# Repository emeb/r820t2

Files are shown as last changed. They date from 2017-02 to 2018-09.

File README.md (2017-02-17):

# r820t2
Breakout PCB design and STM32F0 firmware for the Rafael R820T2 tuner chip

Contents
--------

doc - documents for the chip and PCB design. This includes both the orginal
mfgs datasheet as well as schematic and BOM for the PCB design.

f030_r820t2 - STM32F030 firmware. A simple serial command line interface
to access registers and set frequency & gain parameters.

r820t2_breakout - KiCAD PCB design.

LICENSE
-------

The PCB design is licensed separately from the driver code. Please see
the LICENSE files within each sub-directory.

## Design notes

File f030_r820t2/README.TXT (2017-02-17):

README.TXT

Building
--------

Just run
	make
	
Flashing
--------

1) Ensure openocd isn't running as a server already.

2) Make sure that your STM32F0 Discovery board is connected via USB and the
ST-LINK jumpers are set correctly (this example is for the on-board processor,
so 1-2 and 3-4 should be shorted)

3) run
	make flash

4) Done!

Debugging
---------

1) in a separate window start up openocd as a GDB server
	openocd -f openocd.cfg

2) run gdb with your favorite UI
	ddd --debugger arm-none-eabi-gdb main.elf

3) connect to the server within gdb
	target extended-remote localhost:3333

4) Start debugging!

LICENSE
-------

The r820t2 driver code (r820t2.[ch]) herein originated with the Airspy product
which derived from the Linux driver. Consequently my revisions are subject to
the LICENSE file from those projects.

The CMSIS and StdPeriph directories are from ARM ans ST Microelectronics and
are suject to the licenses therein.

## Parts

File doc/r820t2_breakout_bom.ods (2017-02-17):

Reference | Value | Footprint | Cnt | Qty | Mfg P/N | Distributor | Distributor P/N | Notes
C101 | 0.01uf | Capacitors_SMD:C_0603_HandSoldering | 1 | 1 | C1608X7R1H103K080AA | Mouser | 810-C1608X7R1H103K
C108 | 0.1uf | Capacitors_SMD:C_0603_HandSoldering | 1
C116 | 0.1uf | Capacitors_SMD:C_0603_HandSoldering | 1
C117 | 0.1uf | Capacitors_SMD:C_0603_HandSoldering | 1
C104 | 0.1uf | Capacitors_SMD:C_0603_HandSoldering | 1
C109 | 0.1uf | Capacitors_SMD:C_0603_HandSoldering | 1
C113 | 0.1uf | Capacitors_SMD:C_0603_HandSoldering | 1
C114 | 0.1uf | Capacitors_SMD:C_0603_HandSoldering | 1
C118 | 0.1uf | Capacitors_SMD:C_0603_HandSoldering | 1
C121 | 0.1uf | Capacitors_SMD:C_0603_HandSoldering | 1
C103 | 0.1uf | Capacitors_SMD:C_0603_HandSoldering | 1 | 10 | C1608X7R1E104K080AA | Digi-Key | 445-1316-1-ND
C106 | 1uf | Capacitors_SMD:C_0603_HandSoldering | 1 | 1 | GCM188R71E105KA64D | Mouser | 81-GCM188R71E105KA4D
C110 | 27pf | Capacitors_SMD:C_0603_HandSoldering | 1
C111 | 27pf | Capacitors_SMD:C_0603_HandSoldering | 1
C105 | 27pf | Capacitors_SMD:C_0603_HandSoldering | 1
C107 | 27pf | Capacitors_SMD:C_0603_HandSoldering | 1 | 4 | CL10C270JB8NNNC | Digi-Key | 1276-1086-1-ND
C102 | 330pf | Capacitors_SMD:C_0603_HandSoldering | 1
C119 | 330pf | Capacitors_SMD:C_0603_HandSoldering | 1 | 2 | C0603C331J5GACTU | Digi-Key | 399-1068-1-ND
C120 | 6800pf | Capacitors_SMD:C_0603_HandSoldering | 1 | 1 | GRM1885C1H682JA01D | Digi-Key | 490-11477-1-ND
C112 | 10uf | Capacitors_SMD:C_0805_HandSoldering | 1
C115 | 10uf | Capacitors_SMD:C_0805_HandSoldering | 1 | 2 | EMK212BB7106MG-T | Mouser | 963-EMK212BB7106MG-T
P102 | DNI | Connect:PINTST | 1
P103 | DNI | Connect:PINTST | 1
P108 | DNI | Connect:PINTST | 1
P106 | DNI | Connect:PINTST | 1
P104 | DNI | Connect:PINTST | 1
P107 | DNI | Connect:PINTST | 1
P105 | DNI | Connect:PINTST | 1 | 7
U101 | TWEAALSANF-28.800000 | Crystals:Crystal_SMD_Abracon_ABM3C-4pin_5.0x3.2mm | 1 | 1
Y101 | 28.8MHz | Crystals:Crystal_SMD_HC49-SD | 1 | 1 | 9C-28.800MBBK-T | Digi-Key | 887-2449-1-ND
T101 | TRANSFO4 | footprints:Pulse_SMD_Balun | 1 | 1 | MABAES0060 | Digi-Key | 1465-1317-1-ND
U102 | R820T2 | footprints:QFN-24-1EP_4x4mm_Pitch0.5mm_extended_pad | 1 | 1 | R820T2 | ebay
J101 | SMA | footprints:SMA_END | 1
J102 | SMA | footprints:SMA_END | 1 | 2 | Misc SMA end-launch | ebay
P101 | CONN_01X04 | Pin_Headers:Pin_Header_Straight_1x04_Pitch2.54mm | 1 | 1 | Generic 0.1” breakaway
R111 | 0 | Resistors_SMD:R_0603_HandSoldering | 1
R105 | 0 | Resistors_SMD:R_0603_HandSoldering | 1 | 2 | ERJ-3GEY0R00V | Digi-Key | P0.0GCT-ND
R106 | 10 | Resistors_SMD:R_0603_HandSoldering | 1 | 1 | ERJ-3GEYJ100V | Digi-Key | P10GCT-ND
R101 | 220 | Resistors_SMD:R_0603_HandSoldering | 1
R102 | 220 | Resistors_SMD:R_0603_HandSoldering | 1
R107 | 220 | Resistors_SMD:R_0603_HandSoldering | 1
R108 | 220 | Resistors_SMD:R_0603_HandSoldering | 1 | 4 | ERJ-3GEYJ221V | Digi-Key | P220GCT-ND
R112 | 10k | Resistors_SMD:R_0603_HandSoldering | 1 | 1 | ERJ-3GEYJ103V | Digi-Key | P10KGCT-ND
L102 | 150nh | Resistors_SMD:R_0603_HandSoldering | 1
L103 | 150nh | Resistors_SMD:R_0603_HandSoldering | 1 | 2 | L-14CR15JV4T | Digi-Key | 712-1448-1-ND
R110 | 1k8 | Resistors_SMD:R_0603_HandSoldering | 1 | 1 | ERJ-3GEYJ182V | Digi-Key | P1.8KGCT-ND
R103 | 4k7 | Resistors_SMD:R_0603_HandSoldering | 1
R104 | 4k7 | Resistors_SMD:R_0603_HandSoldering | 1 | 2 | ERJ-3GEYJ472V | Digi-Key | P4.7KGCT-ND
L101 | 8.2nH | Resistors_SMD:R_0603_HandSoldering | 1 | 1 | LQW18AN8N2D00D | Digi-Key | 490-1167-1-ND
R109 | DNI | Resistors_SMD:R_0603_HandSoldering | 1 | 1
U103 | LD1117S33CTR | SOT-223 | 1 | 1 | LD1117S33TR | Digi-Key | 497-1242-1-ND
D101 | BAV99 | TO_SOT_Packages_SMD:SOT-23 | 1 | 1 | BAV99 | Digi-Key | BAV99FSCT-ND

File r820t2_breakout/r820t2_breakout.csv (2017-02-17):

Reference | Value | Footprint | Cnt | Qty | Mfg P/N | Distributor | Distributor P/N | Notes
C101 | 0.01uf | Capacitors_SMD:C_0603_HandSoldering | 1 | 1
C108 | 0.1uf | Capacitors_SMD:C_0603_HandSoldering | 1
C116 | 0.1uf | Capacitors_SMD:C_0603_HandSoldering | 1
C117 | 0.1uf | Capacitors_SMD:C_0603_HandSoldering | 1
C104 | 0.1uf | Capacitors_SMD:C_0603_HandSoldering | 1
C109 | 0.1uf | Capacitors_SMD:C_0603_HandSoldering | 1
C113 | 0.1uf | Capacitors_SMD:C_0603_HandSoldering | 1
C114 | 0.1uf | Capacitors_SMD:C_0603_HandSoldering | 1
C118 | 0.1uf | Capacitors_SMD:C_0603_HandSoldering | 1
C121 | 0.1uf | Capacitors_SMD:C_0603_HandSoldering | 1
C103 | 0.1uf | Capacitors_SMD:C_0603_HandSoldering | 1 | 10 | C1608X7R1E104K080AA | Digi-Key | 445-1316-1-ND
C106 | 1uf | Capacitors_SMD:C_0603_HandSoldering | 1 | 1 | GCM188R71E105KA64D | Mouser | 81-GCM188R71E105KA4D
C110 | 27pf | Capacitors_SMD:C_0603_HandSoldering | 1
C111 | 27pf | Capacitors_SMD:C_0603_HandSoldering | 1
C105 | 27pf | Capacitors_SMD:C_0603_HandSoldering | 1
C107 | 27pf | Capacitors_SMD:C_0603_HandSoldering | 1 | 4
C102 | 330pf | Capacitors_SMD:C_0603_HandSoldering | 1
C119 | 330pf | Capacitors_SMD:C_0603_HandSoldering | 1 | 2
C120 | 6800pf | Capacitors_SMD:C_0603_HandSoldering | 1 | 1
C112 | 10uf | Capacitors_SMD:C_0805_HandSoldering | 1
C115 | 10uf | Capacitors_SMD:C_0805_HandSoldering | 1 | 2 | EMK212BB7106MG-T | Mouser | 963-EMK212BB7106MG-T
P102 | DNI | Connect:PINTST | 1
P103 | DNI | Connect:PINTST | 1
P108 | DNI | Connect:PINTST | 1
P106 | DNI | Connect:PINTST | 1
P104 | DNI | Connect:PINTST | 1
P107 | DNI | Connect:PINTST | 1
P105 | DNI | Connect:PINTST | 1 | 7
U101 | TWEAALSANF-28.800000 | Crystals:Crystal_SMD_Abracon_ABM3C-4pin_5.0x3.2mm | 1 | 1
Y101 | 28.8MHz | Crystals:Crystal_SMD_HC49-SD | 1 | 1
T101 | TRANSFO4 | footprints:Pulse_SMD_Balun | 1 | 1
U102 | R820T2 | footprints:QFN-24-1EP_4x4mm_Pitch0.5mm_extended_pad | 1 | 1
J101 | SMA | footprints:SMA_END | 1
J102 | SMA | footprints:SMA_END | 1 | 2
P101 | CONN_01X04 | Pin_Headers:Pin_Header_Straight_1x04_Pitch2.54mm | 1 | 1
R111 | 0 | Resistors_SMD:R_0603_HandSoldering | 1
R105 | 0 | Resistors_SMD:R_0603_HandSoldering | 1 | 2
R106 | 10 | Resistors_SMD:R_0603_HandSoldering | 1 | 1
R101 | 220 | Resistors_SMD:R_0603_HandSoldering | 1
R102 | 220 | Resistors_SMD:R_0603_HandSoldering | 1
R107 | 220 | Resistors_SMD:R_0603_HandSoldering | 1
R108 | 220 | Resistors_SMD:R_0603_HandSoldering | 1 | 4
R112 | 10k | Resistors_SMD:R_0603_HandSoldering | 1 | 1
L102 | 150nh | Resistors_SMD:R_0603_HandSoldering | 1
L103 | 150nh | Resistors_SMD:R_0603_HandSoldering | 1 | 2
R110 | 1k8 | Resistors_SMD:R_0603_HandSoldering | 1 | 1
R103 | 4k7 | Resistors_SMD:R_0603_HandSoldering | 1
R104 | 4k7 | Resistors_SMD:R_0603_HandSoldering | 1 | 2
L101 | 8.2nH | Resistors_SMD:R_0603_HandSoldering | 1 | 1
R109 | DNI | Resistors_SMD:R_0603_HandSoldering | 1 | 1
U103 | LD1117S33CTR | SOT-223 | 1 | 1
D101 | BAV99 | TO_SOT_Packages_SMD:SOT-23 | 1 | 1

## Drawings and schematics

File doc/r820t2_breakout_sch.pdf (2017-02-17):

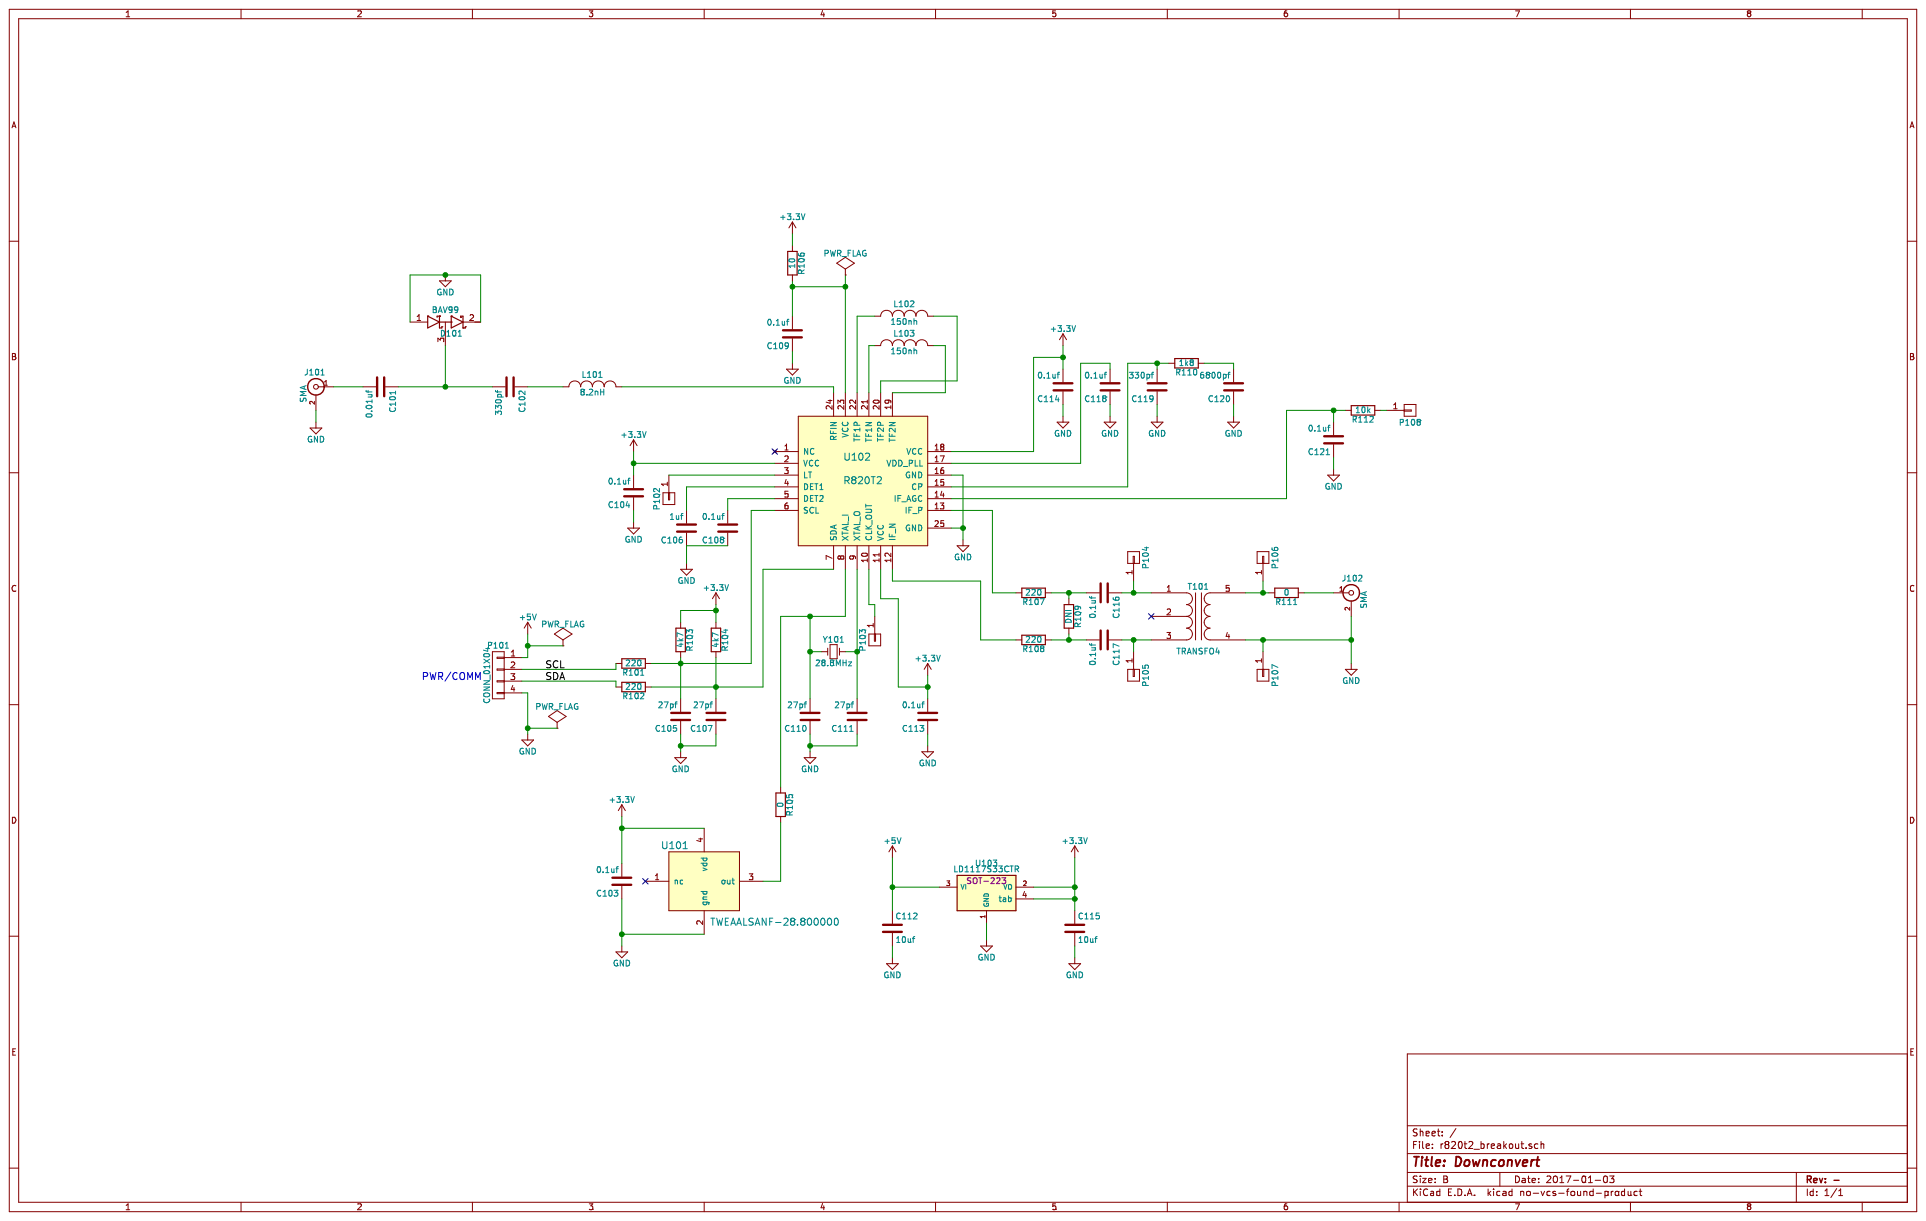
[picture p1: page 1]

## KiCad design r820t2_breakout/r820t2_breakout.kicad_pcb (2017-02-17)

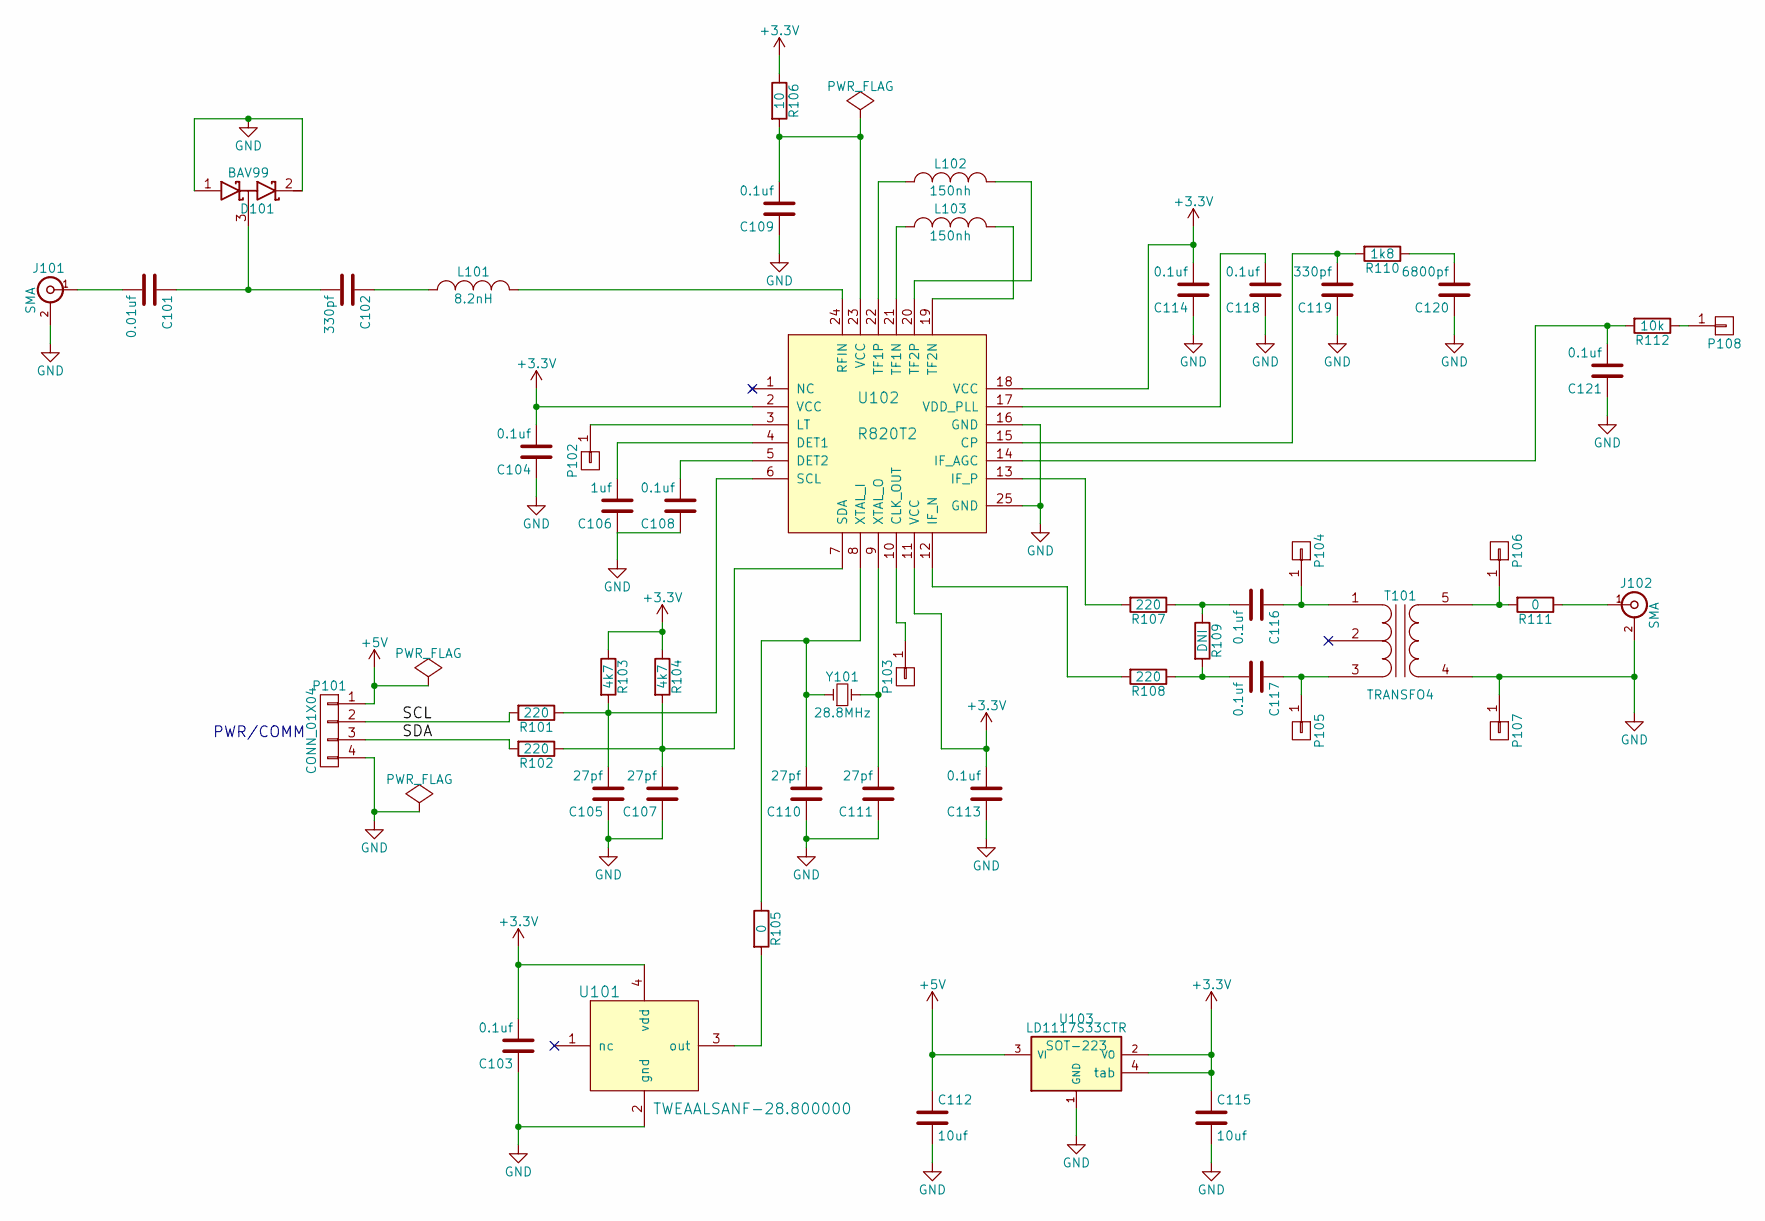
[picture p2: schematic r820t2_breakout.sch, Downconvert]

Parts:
C101: 0.01uf; C_0603_HandSoldering
C102, C119: 330pf; C_0603_HandSoldering
C103, C104, C108, C109, C113, C114, C116, C117, C118, C121: 0.1uf; C_0603_HandSoldering
C105, C107, C110, C111: 27pf; C_0603_HandSoldering
C106: 1uf; C_0603_HandSoldering
C112, C115: 10uf; C_0805_HandSoldering
C120: 6800pf; C_0603_HandSoldering
D101: BAV99; SOT-23
J101, J102: SMA; SMA_END
L101: 8.2nH; R_0603_HandSoldering
L102, L103: 150nh; R_0603_HandSoldering
P101: CONN_01X04; Pin_Header_Straight_1x04_Pitch2.54mm
P102, P103, P104, P105, P106, P107, P108: CONN_01X01; PINTST
R101, R102, R107, R108: 220; R_0603_HandSoldering
R103, R104: 4k7; R_0603_HandSoldering
R105, R111: 0; R_0603_HandSoldering
R106: 10; R_0603_HandSoldering
R109: DNI; R_0603_HandSoldering
R110: 1k8; R_0603_HandSoldering
R112: 10k; R_0603_HandSoldering
T101: TRANSFO4; Pulse_SMD_Balun
U101: TWEAALSANF-28.800000; Crystal_SMD_Abracon_ABM3C-4pin_5.0x3.2mm
U102: R820T2; QFN-24-1EP_4x4mm_Pitch0.5mm_extended_pad
U103: LD1117S33CTR; SOT-223
Y101: 28.8MHz; Crystal_SMD_HC49-SD

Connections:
+3V3: C103.2, C104.2, C113.2, C114.2, C115.1, R103.1, R104.1, R106.1, U101.4 (vdd), U102.2 (VCC), U102.11 (VCC), U102.18 (VCC), U103.2 (VO), U103.4 (tab)
+5V: C112.1, P101.1, U103.3 (VI)
/SCL: P101.2, R101.2
/SDA: P101.3, R102.2
GND: C103.1, C104.1, C105.1, C106.1, C107.1, C108.1, C109.1, C110.1, C111.1, C112.2, C113.1, C114.1, C115.2, C118.1, C119.1, C120.1, C121.1, D101.1 (A), D101.2 (K), J101.2 (Ext), J102.2 (Ext), P101.4, P107.1, T101.4 (S1), U101.2 (gnd), U102.16 (GND), U102.25 (GND), U103.1 (GND)
unnamed: C101.1, C102.2, D101.3 (common)
unnamed: C101.2, J101.1 (In)
unnamed: C102.1, L101.1
unnamed: C105.2, R101.1, R103.2, U102.6 (SCL)
unnamed: C106.2, U102.4 (DET1)
unnamed: C107.2, R102.1, R104.2, U102.7 (SDA)
unnamed: C108.2, U102.5 (DET2)
unnamed: C109.2, R106.2, U102.23 (VCC)
unnamed: C110.2, R105.1, U102.8 (XTAL_I), Y101.1
unnamed: C111.2, U102.9 (XTAL_O), Y101.2
unnamed: C116.1, P104.1, T101.1 (PR1)
unnamed: C116.2, R107.1, R109.1
unnamed: C117.1, P105.1, T101.3 (PR2)
unnamed: C117.2, R108.1, R109.2
unnamed: C118.2, U102.17 (VDD_PLL)
unnamed: C119.2, R110.2, U102.15 (CP)
unnamed: C120.2, R110.1
unnamed: C121.2, R112.2, U102.14 (IF_AGC)
unnamed: J102.1 (In), R111.1
unnamed: L101.2, U102.24 (RFIN)
unnamed: L102.1, U102.20 (TF2P)
unnamed: L102.2, U102.22 (TF1P)
unnamed: L103.1, U102.19 (TF2N)
unnamed: L103.2, U102.21 (TF1N)
unnamed: P102.1, U102.3 (LT)
unnamed: P103.1, U102.10 (CLK_OUT)
unnamed: P106.1, R111.2, T101.5 (S2)
unnamed: P108.1, R112.1
unnamed: R105.2, U101.3 (out)
unnamed: R107.2, U102.13 (IF_P)
unnamed: R108.2, U102.12 (IF_N)

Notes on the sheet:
PWR/COMM

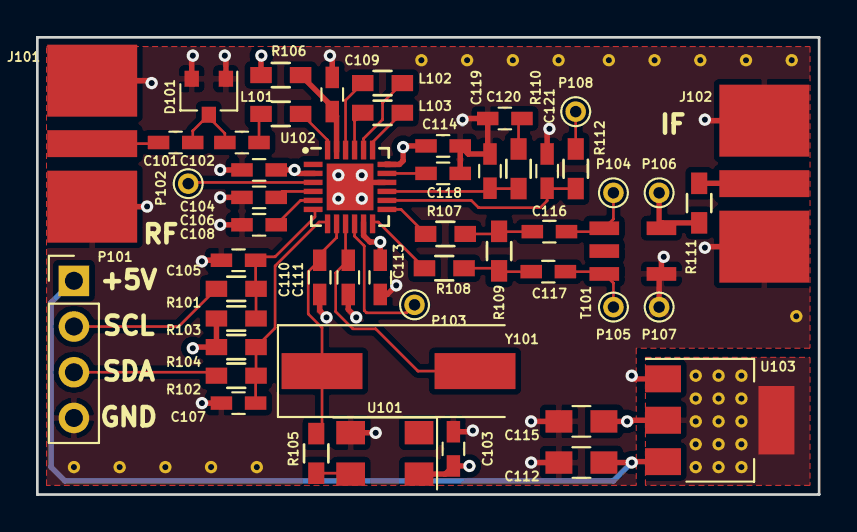
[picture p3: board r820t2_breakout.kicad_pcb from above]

Board: 4 copper layers, 43.4 x 25.4 mm, 52 parts (0 on the bottom side), 36 nets.

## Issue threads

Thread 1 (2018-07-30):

USING MINI DIGITAL TV STICK RTL2832U 820T2 & SDR ON GNRC

aecs18, 2018-07-30:
Good afternoon everyone.I write here to see if any of you know that installation errors I may have had to use the r820t2 in gnu radio companion.

I'm trying to make an FM receiver and other analog TV receiver but when running the program does not receive any type of signal and the view errors, I have: devices not supported. I believe that this is some driver to be installed but I don't know where or how.

The steps that I have followed for installation (Ubuntu 16.04 LTS) have been:

1. Install gnuradio.
2. Install Xenial Xerius specifications (it is supposed to do I need for my version of Ubuntu).
3. Install specifications of gr-osmosdr to enable some features of the chip.

The Stick comes with a CD but i do not know how to install it since, according to the specifications only works for WXP, 2000, Vista, 7 and 8; and it is something that it seems strange to me since I have seen videos where they use this same model of stick to carry out projects in Gnuradio on Ubuntu.

Please, if any of you know that i need to install It would serve as much help as I am a novice programmer and i need to resolve this problem for my project.

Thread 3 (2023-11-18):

Assembly values guide

JBKingdon, 2023-11-18:
Hi,

Many thanks for sharing this breakout board. I'm in the process of making one and like to have a printout of the values for assembly, so I worked on the F.Fab layer a little to get a simple cheat sheet. I've attached a screen grab in case it's useful to anyone else.
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

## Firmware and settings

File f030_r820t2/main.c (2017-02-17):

/*
 * STM32F030 driver for R820T2
 * E. Brombaugh 02-12-2017
 */

#include <string.h>
#include <stdlib.h>
#include <stdio.h>
#include "stm32f0xx.h"
#include "led.h"
#include "systick.h"
#include "usart.h"
#include "printf.h"
#include "r820t2.h"
#include "cmd.h"

int main(void)
{
    uint8_t regs[32], reg;
    int rxchar;
	uint32_t i, tick;
    
	/* initialize the hardware */
	led_init();
	systick_init();
	usart_init();
	init_printf(0,usart_putc);
	
	/* Startup message */
	printf("\r\nSTM32F030 R820T2 driver.\n\r");
	
	/* init R820T2 */
	R820T2_init();
	printf("R820T2 initialized.\n\r");

    /* Loop forever */
	init_cmd();
    tick = systick_gettick() + 100;
	while(1)
	{
		/* UART command processing */
		if((rxchar = usart_getc())!= EOF)
		{
			/* Parse commands */
			cmd_parse(rxchar);
		}
                
		/* nonblocking wait to flash light */
		if(tick < systick_gettick())
		{
            led_toggle(LED1);
            tick = systick_gettick() + 100;
        }
	}
}

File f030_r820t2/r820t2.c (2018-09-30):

/*
 * R820T2.c - R820T2 Clock Generator driver for STM32F030
 * 01-08-2017 E. Brombaugh
 */

#include "r820t2.h"
#include <math.h>
#include "printf.h"
#include "systick.h"

/*
 * I2C stuff
 */
#define R820T2_I2C_ADDRESS   ((0x1A)<<1)	// 0011010+RW - 0x34 (w), 0x35 (r)
#define FLAG_TIMEOUT         ((uint32_t)0x1000)
#define LONG_TIMEOUT         ((uint32_t)(10 * FLAG_TIMEOUT))

/*
 * Freq calcs
 */
#define XTAL_FREQ 28800000
#define CALIBRATION_LO 88000

/* registers */
#define R820T2_NUM_REGS     0x20
#define R820T2_WRITE_START	5

/* initial values from airspy */
/* initial freq @ 128MHz -> ~5MHz IF due to xtal mismatch */
static const uint8_t r82xx_init_array[R820T2_NUM_REGS] =
{
	0x00, 0x00, 0x00, 0x00,	0x00,		/* 00 to 04 */
    /* 05 */ 0x90, // LNA manual gain mode, init to 0
    /* 06 */ 0x80,
    /* 07 */ 0x60,
    /* 08 */ 0x80, // Image Gain Adjustment
    /* 09 */ 0x40, // Image Phase Adjustment
    /* 0A */ 0xA8, // Channel filter [0..3]: 0 = widest, f = narrowest - Optimal. Don't touch!
    /* 0B */ 0x0F, // High pass filter - Optimal. Don't touch!
    /* 0C */ 0x40, // VGA control by code, init at 0
    /* 0D */ 0x63, // LNA AGC settings: [0..3]: Lower threshold; [4..7]: High threshold
    /* 0E */ 0x75,
    /* 0F */ 0xF8, // Filter Widest, LDO_5V OFF, clk out OFF,
    /* 10 */ 0x7C,
    /* 11 */ 0x83,
    /* 12 */ 0x80,
    /* 13 */ 0x00,
    /* 14 */ 0x0F,
    /* 15 */ 0x00,
    /* 16 */ 0xC0,
    /* 17 */ 0x30,
    /* 18 */ 0x48,
    /* 19 */ 0xCC,
    /* 1A */ 0x60,
    /* 1B */ 0x00,
    /* 1C */ 0x54,
    /* 1D */ 0xAE,
    /* 1E */ 0x0A,
    /* 1F */ 0xC0
};

#define ARRAY_SIZE(arr) (sizeof(arr) / sizeof((arr)[0]))

/*
 * Tuner frequency ranges
 * Kanged & modified from airspy firmware to include freq for scanning table
 * "Copyright (C) 2013 Mauro Carvalho Chehab"
 * https://stuff.mit.edu/afs/sipb/contrib/linux/drivers/media/tuners/r820t.c
 */
struct r820t_freq_range
{
  uint16_t freq;
  uint8_t open_d;
  uint8_t rf_mux_ploy;
  uint8_t tf_c;
};

const struct r820t_freq_range freq_ranges[] =
{
  {
  /* 0 MHz */ 0,
  /* .open_d = */     0x08, /* low */
  /* .rf_mux_ploy = */  0x02, /* R26[7:6]=0 (LPF)  R26[1:0]=2 (low) */
  /* .tf_c = */     0xdf, /* R27[7:0]  band2,band0 */
  }, {
  /* 50 MHz */ 50,
  /* .open_d = */     0x08, /* low */
  /* .rf_mux_ploy = */  0x02, /* R26[7:6]=0 (LPF)  R26[1:0]=2 (low) */
  /* .tf_c = */     0xbe, /* R27[7:0]  band4,band1  */
  }, {
  /* 55 MHz */ 55,
  /* .open_d = */     0x08, /* low */
  /* .rf_mux_ploy = */  0x02, /* R26[7:6]=0 (LPF)  R26[1:0]=2 (low) */
  /* .tf_c = */     0x8b, /* R27[7:0]  band7,band4 */
  }, {
  /* 60 MHz */ 60,
  /* .open_d = */     0x08, /* low */
  /* .rf_mux_ploy = */  0x02, /* R26[7:6]=0 (LPF)  R26[1:0]=2 (low) */
  /* .tf_c = */     0x7b, /* R27[7:0]  band8,band4 */
  }, {
  /* 65 MHz */ 65,
  /* .open_d = */     0x08, /* low */
  /* .rf_mux_ploy = */  0x02, /* R26[7:6]=0 (LPF)  R26[1:0]=2 (low) */
  /* .tf_c = */     0x69, /* R27[7:0]  band9,band6 */
  }, {
  /* 70 MHz */ 70,
  /* .open_d = */     0x08, /* low */
  /* .rf_mux_ploy = */  0x02, /* R26[7:6]=0 (LPF)  R26[1:0]=2 (low) */
  /* .tf_c = */     0x58, /* R27[7:0]  band10,band7 */
  }, {
  /* 75 MHz */ 75,
  /* .open_d = */     0x00, /* high */
  /* .rf_mux_ploy = */  0x02, /* R26[7:6]=0 (LPF)  R26[1:0]=2 (low) */
  /* .tf_c = */     0x44, /* R27[7:0]  band11,band11 */
  }, {
  /* 80 MHz */ 80,
  /* .open_d = */     0x00, /* high */
  /* .rf_mux_ploy = */  0x02, /* R26[7:6]=0 (LPF)  R26[1:0]=2 (low) */
  /* .tf_c = */     0x44, /* R27[7:0]  band11,band11 */
  }, {
  /* 90 MHz */ 90,
  /* .open_d = */     0x00, /* high */
  /* .rf_mux_ploy = */  0x02, /* R26[7:6]=0 (LPF)  R26[1:0]=2 (low) */
  /* .tf_c = */     0x34, /* R27[7:0]  band12,band11 */
  }, {
  /* 100 MHz */ 100,
  /* .open_d = */     0x00, /* high */
  /* .rf_mux_ploy = */  0x02, /* R26[7:6]=0 (LPF)  R26[1:0]=2 (low) */
  /* .tf_c = */     0x34, /* R27[7:0]  band12,band11 */
  }, {
  /* 110 MHz */ 110,
  /* .open_d = */     0x00, /* high */
  /* .rf_mux_ploy = */  0x02, /* R26[7:6]=0 (LPF)  R26[1:0]=2 (low) */
  /* .tf_c = */     0x24, /* R27[7:0]  band13,band11 */
  }, {
  /* 120 MHz */ 120,
  /* .open_d = */     0x00, /* high */
  /* .rf_mux_ploy = */  0x02, /* R26[7:6]=0 (LPF)  R26[1:0]=2 (low) */
  /* .tf_c = */     0x24, /* R27[7:0]  band13,band11 */
  }, {
  /* 140 MHz */ 140,
  /* .open_d = */     0x00, /* high */
  /* .rf_mux_ploy = */  0x02, /* R26[7:6]=0 (LPF)  R26[1:0]=2 (low) */
  /* .tf_c = */     0x14, /* R27[7:0]  band14,band11 */
  }, {
  /* 180 MHz */ 180,
  /* .open_d = */     0x00, /* high */
  /* .rf_mux_ploy = */  0x02, /* R26[7:6]=0 (LPF)  R26[1:0]=2 (low) */
  /* .tf_c = */     0x13, /* R27[7:0]  band14,band12 */
  }, {
  /* 220 MHz */ 220,
  /* .open_d = */     0x00, /* high */
  /* .rf_mux_ploy = */  0x02, /* R26[7:6]=0 (LPF)  R26[1:0]=2 (low) */
  /* .tf_c = */     0x13, /* R27[7:0]  band14,band12 */
  }, {
  /* 250 MHz */ 250,
  /* .open_d = */     0x00, /* high */
  /* .rf_mux_ploy = */  0x02, /* R26[7:6]=0 (LPF)  R26[1:0]=2 (low) */
  /* .tf_c = */     0x11, /* R27[7:0]  highest,highest */
  }, {
  /* 280 MHz */ 280,
  /* .open_d = */     0x00, /* high */
  /* .rf_mux_ploy = */  0x02, /* R26[7:6]=0 (LPF)  R26[1:0]=2 (low) */
  /* .tf_c = */     0x00, /* R27[7:0]  highest,highest */
  }, {
  /* 310 MHz */ 310,
  /* .open_d = */     0x00, /* high */
  /* .rf_mux_ploy = */  0x41, /* R26[7:6]=1 (bypass)  R26[1:0]=1 (middle) */
  /* .tf_c = */     0x00, /* R27[7:0]  highest,highest */
  }, {
  /* 450 MHz */ 450,
  /* .open_d = */     0x00, /* high */
  /* .rf_mux_ploy = */  0x41, /* R26[7:6]=1 (bypass)  R26[1:0]=1 (middle) */
  /* .tf_c = */     0x00, /* R27[7:0]  highest,highest */
  }, {
  /* 588 MHz */ 588,
  /* .open_d = */     0x00, /* high */
  /* .rf_mux_ploy = */  0x40, /* R26[7:6]=1 (bypass)  R26[1:0]=0 (highest) */
  /* .tf_c = */     0x00, /* R27[7:0]  highest,highest */
  }, {
  /* 650 MHz */ 650,
  /* .open_d = */     0x00, /* high */
  /* .rf_mux_ploy = */  0x40, /* R26[7:6]=1 (bypass)  R26[1:0]=0 (highest) */
  /* .tf_c = */     0x00, /* R27[7:0]  highest,highest */
  }
};

/*
 * local vars
 */
uint8_t r820t_regs[R820T2_NUM_REGS];
uint32_t r820t_freq;
uint32_t r820t_xtal_freq;
uint32_t r820t_if_freq;

/*
 * exception handler for I2C timeout
 */
uint32_t R820T2_TIMEOUT_UserCallback(void)
{
  /* Block communication and all processes */
  while (1)
  {   
  }
}

/*
 * Send a block of data to the R820T2 via I2C
 */
void R820T2_i2c_write(uint8_t reg, uint8_t *data, uint8_t sz)
{
	uint32_t  Timeout;
	
#if 0
    uint16_t i;
    printf("R820T2_i2c_write(%d, %d, %d)\n\r", reg, data, sz);
	for(i=0;i<sz;i++)
    {
        printf("%2d : 0x%02X\n\r", i, data[i]&0xff);
		systick_delayms(10);
    }
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

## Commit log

2017-02-17 Initial code commit
    [r820t2_breakout.csv, r820t2_breakout.kicad_pcb, r820t2_breakout.sch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]
2017-02-17 Moved top level MIT license to KiCAD project
2018-09-30 Fix out of bounds read in R820T2_init procedure
    [r820t2.c]

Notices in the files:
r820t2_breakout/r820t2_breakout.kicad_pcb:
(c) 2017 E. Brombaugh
